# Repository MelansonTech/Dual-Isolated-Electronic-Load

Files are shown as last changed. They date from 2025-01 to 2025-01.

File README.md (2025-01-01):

# Dual Isolated Electronic Load
 Project: Dual Module Electronic Load with Voltage/Current Ranges and Nextion Touchscreen UI Overview: This project involves the design and development of a dual module electronic load system, which allows users to simulate a variable load on a power supply or battery. The system is capable of handling three distinct voltage levels (400V, 60V, and 20V) and three current ranges (0.35A, 3A, and 10A), offering flexibility for testing a wide range of power supplies and devices. The system incorporates a Nextion touchscreen UI for an intuitive and interactive user experience, enabling users to easily control and monitor the parameters of each module.  Key Features: Dual Module Design: Two independent load modules that can operate separately or in tandem, providing flexibility for different applications. Selectable Voltage and Current Ranges: The system supports three voltage levels (400V, 60V, and 20V) and three current ranges (0.35A, 3A, and 10A) for both modules. Nextion Touchscreen Interface: A user-friendly touchscreen interface that displays real-time data and allows users to control the load settings, select voltage and current ranges, and view system status. High Precision and Accuracy: The design ensures that the voltage and current are accurately regulated, making it suitable for testing power supplies, batteries, and other electronic components. System Components: Nextion Touchscreen: An HMI (Human-Machine Interface) touchscreen that provides an interactive interface for setting and monitoring the load parameters. The touchscreen is connected to the controller, allowing the user to select the voltage and current range for each module. Dual Electronic Load Modules: Each module is capable of handling the specified voltage and current ranges. These modules have precise control circuitry for drawing the desired current from the power source. Controller Circuit: A microcontroller (e.g., Arduino or STM32) processes inputs from the touchscreen and adjusts the load's resistance to regulate the current and voltage as per the selected settings. Power Handling Circuitry: The load modules include MOSFETs, resistors, and current-sensing components to handle the power dissipation for each voltage/current range. Cooling System: Due to the potential heat dissipation in high-power testing, the system includes passive or active cooling mechanisms such as heatsinks or fans. Working Principle: Voltage and Current Control: Each module has a set of switches or digital potentiometers to control the voltage and current. The user selects the desired voltage level (400V, 60V, or 20V) and the corresponding current range (0.35A, 3A, or 10A) using the Nextion touchscreen UI.  Load Regulation: The microcontroller processes the user inputs and adjusts the internal control circuitry (e.g., PWM control for MOSFETs) to simulate the required load on the power supply. This ensures that the current drawn is within the selected range while maintaining the appropriate voltage level.  Nextion Touchscreen Interface: The touchscreen displays real-time information, including:  Selected voltage and current range for both modules Real-time voltage, current, and power measurements Operational status, including any error or fault conditions Graphical representation of load performance (optional) The touchscreen allows the user to dynamically change the load settings and immediately observe the effects.  Feedback Loop: The system continuously monitors the output from the load modules, adjusting the load resistance to maintain the target current. The microcontroller is also responsible for ensuring the load operates within safe thermal limits by regulating the current drawn.  Applications: Power Supply Testing: Perfect for testing and simulating loads on power supplies with varying output voltage and current capabilities. Battery Testing: Ideal for testing battery discharge characteristics across different current ranges and voltages. Prototyping and R&D: Useful in research and development environments for testing power devices and components with adjustable load conditions. Quality Assurance and Validation: Can be used in production environments to validate the performance of power electronics devices, ensuring they meet voltage and current specifications. Design Considerations: Precision Control: The system must maintain accurate voltage and current regulation, especially when switching between different voltage and current ranges. Heat Dissipation: Since electronic loads can dissipate significant power as heat, the design must ensure proper thermal management, especially for higher voltage/current settings. Safety: The system must incorporate over-voltage, over-current, and over-temperature protection to ensure safe operation, especially when dealing with high voltages (e.g., 400V). User Interface: The Nextion touchscreen UI should be intuitive, with clear labeling, graphical representation of real-time data, and responsive controls for easy operation. Power Supply: The design needs to support a high-power input for the load modules, ensuring stable and reliable operation when high current and voltage are required. Challenges: Voltage Isolation: Ensuring safe operation at high voltages (up to 400V) requires proper isolation between control circuits and high-voltage components to prevent damage or injury. Load Switching: The system needs to ensure smooth transitions between voltage/current ranges to avoid sudden spikes or disruptions in the load. Thermal Management: Managing heat generated by high-current operation is crucial to ensure the longevity and stability of the electronic load modules. Conclusion: This Dual Module Electronic Load with Nextion Touchscreen UI represents a versatile, user-friendly solution for testing power supplies, batteries, and other electrical systems across a range of voltage and current levels. The integration of a Nextion touchscreen enhances the user experience, providing real-time monitoring and easy configuration of the load settings. Whether used in research, development, or quality assurance, this electronic load system provides a reliable and precise solution for simulating various load conditions.

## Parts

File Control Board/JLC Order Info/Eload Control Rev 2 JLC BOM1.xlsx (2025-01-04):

Comment | Designator | Footprint | LCSC Part #（optional）
Capacitor; Ceramic; Cap 0.1 uF; Tol 5%; Vol-Rtg 50 VDC; SMT; 0805; X7R; Tape & Reel | C1, C2, C3, C4, C5, C6,C7, C8, C12, C13, C14, C15, C16, C17, C19, C20, C21, C22, C23, C24, C25, C26, C29, C31, C32, C37, C38, C39, C40,C9 | 0805_C | C49678
Cap,SMD,MLCC,2.2uF 25V X7R 10%,0805 | C10, C33, C34, C35, C36,C18, C28 | 0805_C | C49217
CAP CER 10PF 50V C0G/NP0 0805 | C30 | 0805_C | C1785
RES SMD 10K OHM 1% 1/8W 0805 | R1, R2, R5, R6, R25, R26 | 0805_R | C17414
CHIP RESISTOR - SURFACE MOUNT 3.3KOHMS ±1% 1/8W 0805 ROHS | R13, R14, R15, R18, R19, R20, R21 | 0805_R | C26010
RES SMD 33 OHM 5% 1/8W 0805 | R16, R17 | 0805_R | C17634
CHIP RESISTOR - SURFACE MOUNT 22KOHMS ±1% 1/8W 0805 ROHS | R22, R24 | 0805_R | C17560
100 kOhms ±1% 0.125W, 1/8W Chip Resistor 0805 (2012 Metric) Thick Film | R23 | 0805_R | C17407
Res Thick Film 0805 1K Ohm 5% 0.125W(1/8W) ±200ppm/C Molded SMD Automotive Paper T/R | R3, R4, R7, R8, R9, R10,R11 | 0805_R | C17513

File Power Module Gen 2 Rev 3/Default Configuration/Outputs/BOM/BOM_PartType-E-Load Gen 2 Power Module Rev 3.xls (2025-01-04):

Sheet: BOM Report
Bill of Materials |  |  | <Parameter Title not found>
Source Data From: |  | E-Load Gen 2 Power Module Rev 3.PrjPcb
Project: |  | E-Load Gen 2 Power Module Rev 3.PrjPcb
Variant: |  | None
Creation Date: | 4/10/2021 | 2:47:32 PM
Print Date: | 2021-04-10 | 14:47:53
Production Quantity: | 100
Currency | CAD
Footprint | Comment | LibRef | Designator | Description | Quantity | Supplier 1 | Supplier Part Number 1 | Supplier Unit Price 1 | Supplier Order Qty 1 | Supplier Subtotal 1 | Manufacturer 1 | Manufacturer Part Number 1
Cap,0805 | Cap | Cap,0805,100nf,50V,5%,08055C104JAT2A | C1, C2, C3 | Capacitor; Ceramic; Cap 0.1 uF; Tol 5%; Vol-Rtg 50 VDC; SMT; 0805; X7R; Tape & Reel | 3
SOD123 | MMSZ4705T1G | diode,Zener, 18V,500mW, SOD123,MMSZ4705T1G | D2 | Zener Diode 18V 500mW ±5% Surface Mount SOD-123 | 1
4-ESIP with Heat Sink | Vishay PB3510-E3/45 | diode, bridge, 35A, 1000V, PB3510-E3/45 | DB1 | RECTIFIER BRIDGE 1000V 35A PB | 1 | Newark
Fuse,TH,Vertical,0505030.MXEP | FUSE CERAMIC 30A 500VAC/VDC 3AB | Fuse,30A,500VAC/VDC,Leaded | F1, F2 | FUSE CERAMIC 30A 500VAC/VDC 3AB | 2
Connector,TE,3-Pin,Male,Vert,2-644861-3 | 2-644861-3 | Conntector, though hole, TE, 3pin, 2.54mm,2-644861-3 | J1 | Connector Header Through Hole 3 position 0.100" (2.54mm) | 1
Keystone 8197 | wire teminal, lugs, screw, Keystone 8197 | wire teminal, lugs, screw, Keystone 8197 | J2, J3, J4, J5 | WRIGHT TOOL 8197 Socket, 1 In Dr, 3-1/8 In, 12 Pt, Std. More details: Socket, Drive Size 1 In., Number of Points 12, ... | 4
conn, molex, 0.1", 4 pin | 0022112042 | Connector,Through Hole,Molex,2.54mm,4Pin,Vert | J6 | Connector Header Through Hole 4 position 0.100" (2.54mm) | 1
Conn, JST, 4 pin, 2mm spacing Right Angle | JST B4B-PH-K-S(LF)(SN) | Conntector, though hole, JST, 4pin, 2mm,B4B-PH-K-S(LF)(SN) | J7 | PH Series 4 Position 2 mm Pitch Through Hole Crimp Top Entry Shrouded Header | 1 | Farnell
Standoff,Hex,M3,8mm | M3 hex Standoff | Standoff, M3, Hex | M1, M2, M3, M4, M5 | HEX STANDOFF M3,generic | 5
Mod,ELoad Gen 2 Rev 1 Support | Support PCBA | Mod,Eload Gen 2 rev 1 Support and Control | MOD1 | Eload Gen 2 Support PCBA | 1
NTC,TH,2.54mm Lead Spacing,NTCLE100E3103JT2 | NTCLE100E3103JT2 | Sensor,Temp,NTC,10Kohm,0.75%, NTCLE100E3103JT2 | NTC1 | THERMISTOR NTC 10KOHM 3977K BEAD | 1
DUAL TO-247-RA WITH HEATSINK | Diode | CC Load Power Module | PM1 | Dual RA Mosfet TO-247 with CPU cooler | 1
SOT23-3 | 2N7002ET1G | MOSFET,N-Channel,SOT23,0.25A,60V,2N7002ET1G | Q1, Q2, Q3 | Small Signal MOSFET, 60 V, 310 mA, Single, N-Channel, 3-Pin SOT-23, Pb-Free, Tape and Reel | 3 | Digi-Key | 2N7002ET1GOSCT-ND | 0.12501 | 300 | $37.50 | ON Semiconductor | 2N7002ET1G
DPAK,3-Leads | Infineon IRFR8314TRPBF | Mosfet,Dpak, Nchannel,90A,30V, IRFR8314TRPBF | Q4, Q5, Q6, Q7 | Single N-Channel 30 V 2.2 mOhm 36 nC HEXFET® Power Mosfet - DPAK | 4
Res 2512 | Res1 | Res,2512,10mO,3.00W,±1%,CRA2512-FZ-R010ELF | R1, R2 | Resistor; Metal Film; Res 0.01 Ohms; Pwr-Rtg 3 W; Tol 1%; SMT; 2512; Current Sense | 2
Fuse,PTC,10mmPitch,Radial, Disc | PTR030V0800-BK | Fuse,Resettable,8A,30V,ThoughHole,PTR030V0800-BK | R3, R10 | PTC RESET FUSE 30V 8A RADIAL | 2 | Digi-Key | PTR030V0800-BK-ND | 0.67933 | 200 | $135.87 | Eaton Bussmann | PTR030V0800-BK
Shunt,2512,SMD,Kalvin conn | Ohmite LVM25FVR030E-TR | Res, 2512, shunt, 30mO,1W, LVM25FVR030E-TR | R4 | Resistors; Current Sense; SMD 1W 0.030 OHM 1% | 1
Res,1206 | Res,1206,0.330Ohm,shunt,0.75W,1%,50ppm,KRL1632E-M-R330-F-T5 | Res,1206,0.330Ohm,shunt,0.75W,1%,50ppm,KRL1632E-M-R330-F-T5 | R5 | RES 0.33 OHM 1% 3/4W 1206 | 1 | Digi-Key | 408-1588-1-ND | 0.23144 | 100 | $23.14 | Susumu | KRL1632E-M-R330-F-T5
Res,2827,4W | CSSH2728FT10L0 | Res,2827,shunt,10mO,1%,15ppm,CSSH2728FT10L0 | R6 | 10 mOhms ±1% 4W Chip Resistor Wide 2827 (7067 Metric), 2728 Automotive AEC-Q200, Current Sense Metal Foil | 1
res, 0805, HD | Vishay / Dale CRCW080510K0FKTA | Res,0805,10.0kO,1%,100 ppm,CRCW080510K0FKTA | R7, R8, R9 | RES SMD 10K OHM 1% 1/8W 0805 | 3
 |  |  |  |  | 39 |  |  |  |  | $196.51
Approved |  | Notes

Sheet: Project Information
Project Full Path | E:\OneDrive\Shawn\electronic load\Circuit Studio\Rev 2\Power Module Gen 2 Rev 3\E-Load Gen 2 Power Module Rev 3.PrjPcb
Project Filename | E-Load Gen 2 Power Module Rev 3.PrjPcb
Variant Name | None
Data-Source Filename | E-Load Gen 2 Power Module Rev 3.PrjPcb
Data-Source Full Path | E:\OneDrive\Shawn\electronic load\Circuit Studio\Rev 2\Power Module Gen 2 Rev 3\E-Load Gen 2 Power Module Rev 3.PrjPcb
Title | <Parameter Title not found>
Total Quantity | 39
Report Time | 2:47:32 PM
Report Date | 4/10/2021
Report Date & Tine | 4/10/2021 2:47:32 PM
Output Name | BOM_PartType
Output Type | BOM_PartType
Output Generator Name | BOM
Output Generator Description | Bill of Materials

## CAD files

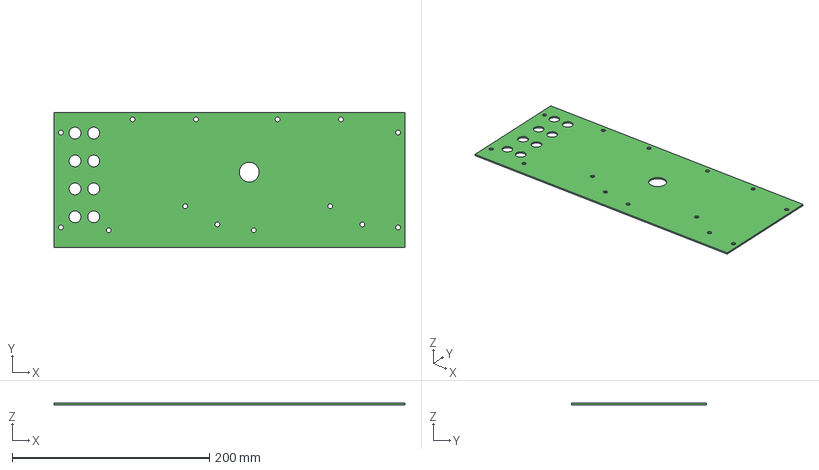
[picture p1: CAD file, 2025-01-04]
3D CAD Files/Gen 2 rev 2/Eload Gen 2 front panel Rev 2.step
356.0 x 137.0 x 1.65 mm

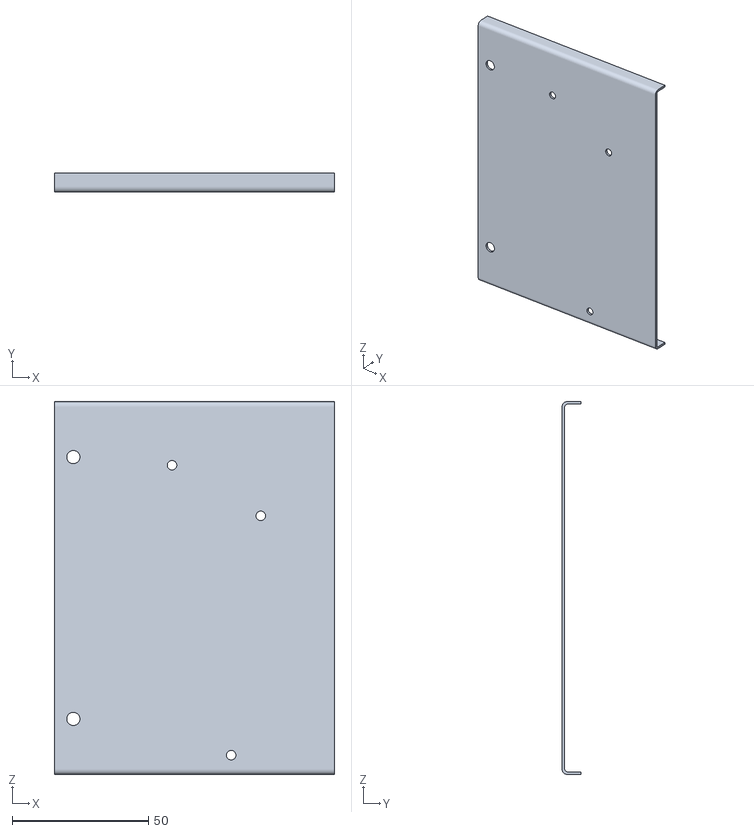
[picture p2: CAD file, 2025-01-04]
3D CAD Files/Gen 2 rev 2/STLs/Front mounting panel - test prints/Body1.stl
103.0 x 7.00 x 137.0

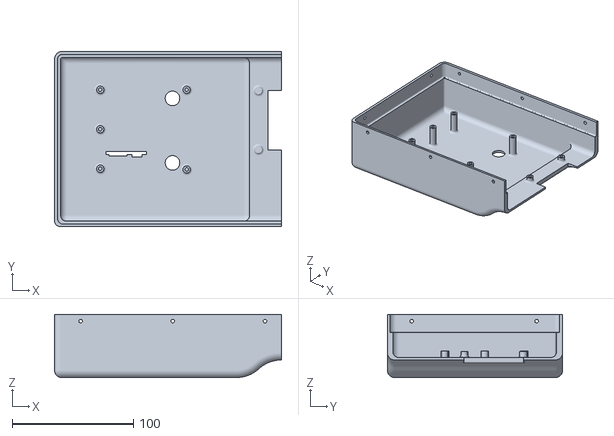
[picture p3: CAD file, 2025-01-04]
3D CAD Files/Gen 2 rev 2/STLs/Front Panel pt3.stl
187.1 x 144.5 x 52.0

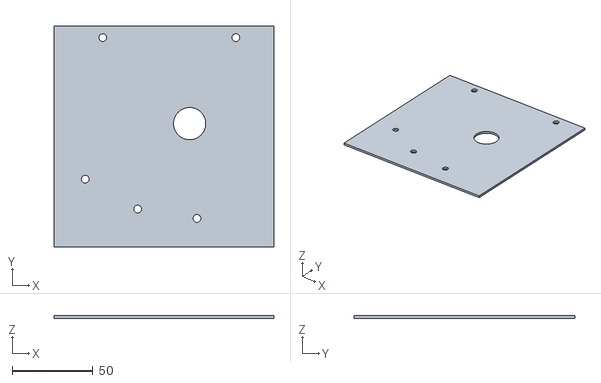
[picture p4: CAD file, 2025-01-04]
3D CAD Files/Gen 2 rev 2/STLs/PCB Front Panel/Body3.stl
136.6 x 137.0 x 1.65

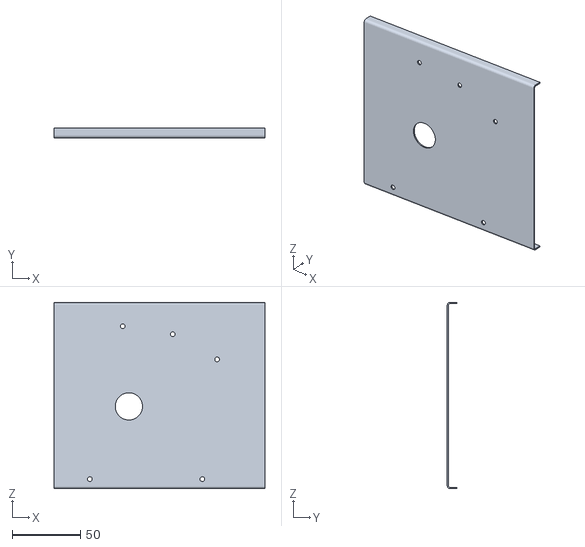
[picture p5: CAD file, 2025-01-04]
3D CAD Files/Gen 2 rev 2/STLs/Front mounting panel - test prints/Body3.stl
155.0 x 7.00 x 137.0

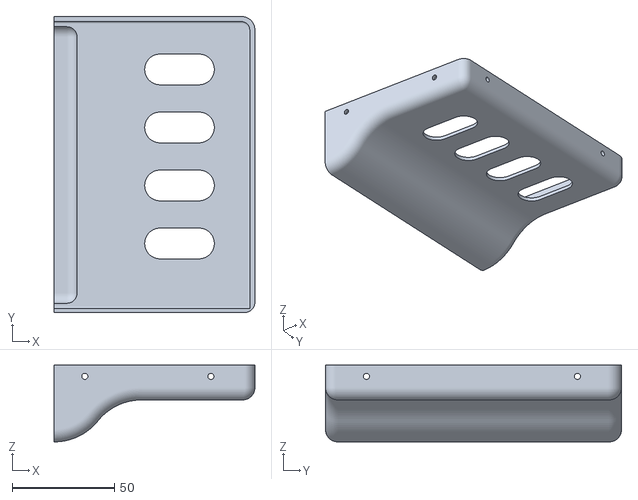
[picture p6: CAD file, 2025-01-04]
3D CAD Files/Gen 2 rev 2/STLs/Front Panel pt1.stl
98.0 x 144.5 x 37.5

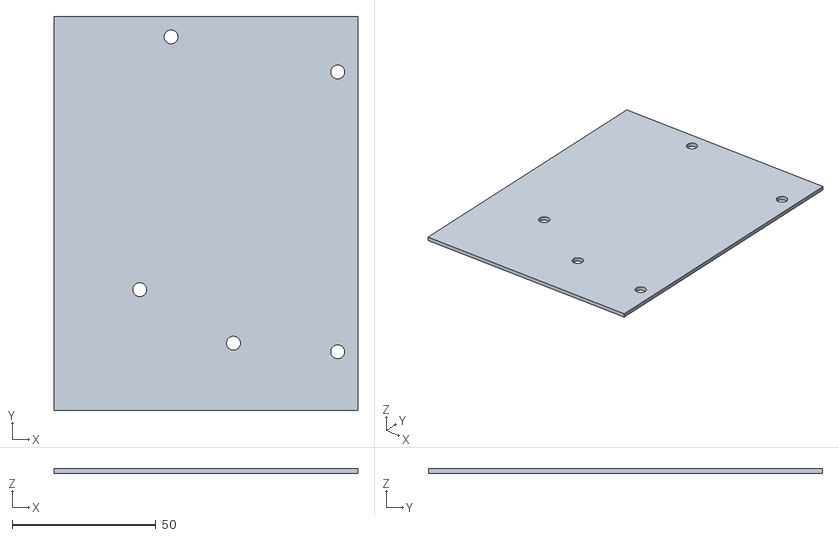
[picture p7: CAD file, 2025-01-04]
3D CAD Files/Gen 2 rev 2/STLs/PCB Front Panel/Body1.stl
105.6 x 137.0 x 1.65

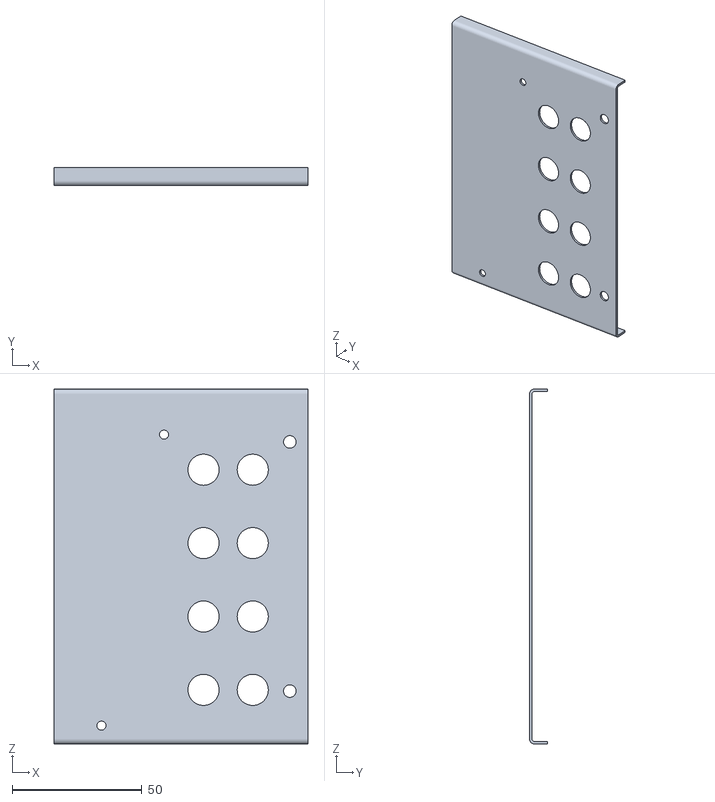
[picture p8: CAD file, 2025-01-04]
3D CAD Files/Gen 2 rev 2/STLs/Front mounting panel - test prints/Body2.stl
98.0 x 7.00 x 137.0

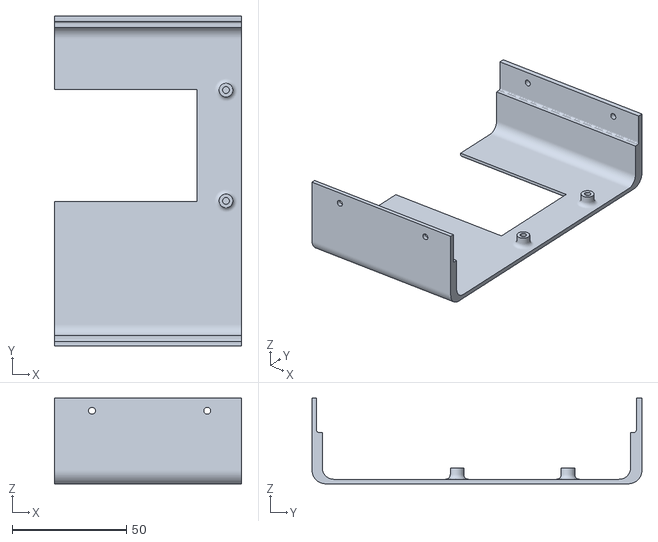
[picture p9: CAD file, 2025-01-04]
3D CAD Files/Gen 2 rev 2/STLs/Front Panel pt2.stl
81.9 x 144.5 x 37.5

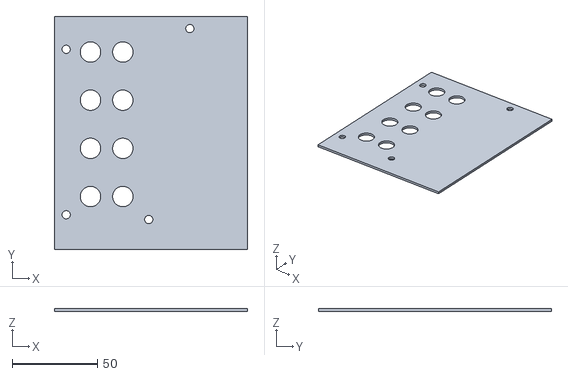
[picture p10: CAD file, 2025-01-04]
3D CAD Files/Gen 2 rev 2/STLs/PCB Front Panel/Body2.stl
113.8 x 137.0 x 1.65

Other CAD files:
3D CAD Files/Gen 2 rev 2/Eload Gen 2 front panel Rev 1.step

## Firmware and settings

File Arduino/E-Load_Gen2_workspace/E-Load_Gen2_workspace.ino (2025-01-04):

#include <SD_t3.h>

// inclue teensy IIC library Files

#include <i2c_t3.h>

//encoder library file

#include <Encoder.h>

//SD card library files

#include <SPI.h>
#include <SD.h>


// Nextion display library files

#include <Nextion.h>
#include <SoftwareSerial.h>
#define HWserial Serial1
#define DBserial Serial

// initialize the encoder by associating any needed encoder interface pins
// encoder pin use definitions

const int CCWA = 27, CWA = 28;
const int CCWB = 2, CWB = 30;
Encoder LDA_Knob(CCWA, CWA);
Encoder LDB_Knob(CCWB, CWB);

// setup digial PIN use definitions

const int LDA_PB = 29;                // LDA Encoder P\B on\off push button
const int LDB_PB = 14;                // LDB Encoder P\B on\off push button
const int SDcard_CS = 10;             // SD card chip select

// ***IIC Pin Use definitions

const int IICData = 18;
const int IICCLK = 19;

// IIC Variables

int LDA_ADD = 0x44; //LDA IIC address
int LDB_ADD = 0x54; //LDA IIC address

#define SetPointChange      0x10
#define modeChange          0x20
#define onOffStateChange    0x30
#define voltRangeChange     0x40
#define currentRangeChange  0x50
#define ADCReadingVolt      0x60
#define ADCReadingCurrent   0x70
#define ADCReadingTemp      0x80
#define ADCReadingRequest   0x90
#define RangeStatusRequest  0xA0


// digi-POT Load A Constants
const int potADD_1 = B0101111;; //I2C address of digital pot 2 (U2)(Write)Load A
const int potADD_2 = B0101110; //I2C address of digital pot 2 (U2)(Write)Load B
const int potInstrucSelB =  0x80; //Instuction POT B Select
const int potInstrucSelA =  0x00; //Instuction POT A Select
const int potInstrucReset = B01000000; //Instuction Reset
const int potInstrucSD =    B00100000; //Instuction ShutDownSelect
const int potInstrucO1 =    B00010000; //Instuction O1 State Change
const int potInstrucO2 =    B00001000; //Instuction O2 State Change

const int Vamp_Range_Low = 0xAF;
const int Vamp_Range_Med = 0x46;
const int Vamp_Range_High = 0x0A;

const float CSLowandVSHIGH = 2500; // Constant resistance Gain
const float CSLowandVSLow = 130; // Constant resistance Gain
const float Voffset = 1860;
float CR_SP_GAIN = CSLowandVSHIGH;

// Load limits

const float maxCurrentRangeLow = 0.35;
const float maxCurrentRangeMed = 3;
const float maxCurrentRangeHigh = 10;

const float VinMaxRangeHigh = 400;
const float VinMaxRangeMed = 60;
const float VinMaxRangeLow = 20;


//Moving average filteres sample size

//int MAF_sizeFast = 5;  // max value is 500 (array is set to 500)
int MAF_sizeSlow = 1; // max value is 500 (array is set to 500)

// SD Card Variables

unsigned int SD_log_count = 0;
unsigned int SD_ss_count = 0;
unsigned int long SD_log_active = 0;



// structs

struct VARS

{


  uint32_t capVal;
  bool StateNow;
  bool StateLast;
  float setVal;
  float calibrated;
  float calGain;
  float calOffset;
  float filteredFast;
  float filteredSlow;
  float ChangeDetectRef;
  // float ARRFast[1];
  float ARRSlow[50];
  int indexFast;
  int indexSlow;
  bool ChangeDetectFlag = 1;
  int range;
  String NexRecieve;
  float CalHighMeas;
  float CalLowMeas;
  float CalHighRead;
  float CalLowRead;
  float offsetRead;
  float offsetMeas;


};

struct SENSE {

  struct VARS SetPoint;
  struct VARS ENCODER;
  struct VARS temp;
  struct VARS volt;
  struct VARS current;
  struct VARS Power;
  struct VARS Mode;
  struct VARS Button;
  float power;
  float CurrentMax;
  int voltageLimit;
  int CurrentLimit;
  int SetPointLow;
  int SetPointHigh;
  int SetPointOffSet;
  String Units;

};


struct SENSE LDA;
struct SENSE LDB;

// nex dual state button cap variables

uint32_t LDACal = 0;
uint32_t LDBCal = 0;
uint32_t LDA_OnOff_State = 0;
uint32_t LDB_OnOff_State = 0;


// encoder variables

long newPositionA;
long newPositionB; // stores the encoder position afer a read
int pointerPosition; // used to set the position of the menu selection icon.

unsigned long int CurrentPage = 10;  // Nextion - Create a variable to store which page is currently loaded

//**************************button pressed flags

uint32_t CalVoltHighFlag = 0;
uint32_t CalVoltLowFlag = 0;

uint32_t CalAmpHighFlag = 0;
uint32_t CalAmpLowFlag = 0;

uint32_t tVoffSetFlag = 0;
uint32_t tIoffSetFlag = 0;

uint32_t bVrangeCalFlag = 0;
uint32_t bIrangeCalFlag = 0;

uint32_t bcaliVoltSlopeFlag = 0;
uint32_t bcaliVoltOffFlag = 0;

uint32_t bcaliCurrSlopeFlag = 0;
uint32_t bcaliCurrOffFlag = 0;

uint32_t CalVoffSetFlag = 0;
uint32_t CalIoffSetFlag = 0;

uint32_t BcalIDefFlag = 0;
uint32_t BcalVDefFlag = 0;

uint32_t KPEFlag = 0;
uint32_t KPXFlag = 0;

uint32_t KPAFlag = 0;
uint32_t KPBFlag = 0;

uint32_t dsbCaLIset = 0;

uint32_t LoadA_On_Off_BState_Cap = 0;
uint32_t LoadB_On_Off_BState_Cap = 0;
uint32_t LoadA_ModeSel_Cap = 0;
uint32_t LoadB_ModeSel_Cap = 0;
uint32_t LoadA_IrangeSel_Cap = 0;
uint32_t LoadB_IrangeSel_Cap = 0;
uint32_t LoadA_VrangeSel_Cap = 0;
uint32_t LoadB_VrangeSel_Cap = 0;



//**************************button pressed flags End

bool Relay_enable = 0;
bool RelayTimerStart = 0;

int RelayTimerRef = 0;
float Relay_onTime = 0;
float Relay_period = 0;

float overTemp = 60; // calibrated over temp fault threshold value
const float PowerLimit = -200; // calibrated over power fault threshold value

//***************************Nextion widget Declarations


//***********declare buttons

//page 1 buttons

NexButton PgSelStatic = NexButton(1, 1, "PgSelStatic");  // Button added
NexButton PgSelDyn = NexButton(1, 2, "PgSelDyn");  // Button added
NexButton PgSelAuto = NexButton(1, 3, "PgSelAuto");  // Button added
NexButton PgSelCal = NexButton(1, 4, "PgSelCal");  // Button added


//Page 2 buttons


NexDSButton LoadA_ON_OFF = NexDSButton(2, 5, "LoadA_ON_OFF");  // Button added
NexDSButton LoadB_ON_OFF = NexDSButton(2, 6, "LoadB_ON_OFF");  // Dual state button added

NexDSButton RunDataLog = NexDSButton(2, 27, "RunDataLog");  // Dual state button added
NexDSButton TakeSnapShot = NexDSButton(2, 33, "TakeSnapShot");  // Dual state button added




//Page 3 buttons

NexDSButton LDA_Bmode = NexDSButton(3, 2, "LDA_Bmode");  // Button added
NexDSButton LDB_Bmode = NexDSButton(3, 3, "LDB_Bmode");  // Button added
NexDSButton LDA_B_VR = NexDSButton(3, 7, "LDA_B_VR");  // Button added
NexDSButton LDB_B_VR = NexDSButton(3, 4 , "LDB_B_VR"); // Button added
NexDSButton LDA_B_IR = NexDSButton(3, 6, "LDA_B_IR");  // Button added
NexDSButton LDB_B_IR = NexDSButton(3, 5, "LDB_B_IR");  // Button added

//Page 4 buttons

NexDSButton bcaliVoltSlope = NexDSButton(4, 21, "bcaliVoltSlope");  // Button added
NexDSButton bcaliCurrSlope = NexDSButton(4, 22, "bcaliCurrSlope");  // Button added
NexDSButton BcalVDef = NexDSButton(4, 23, "BcalVDef"); // Button added
NexDSButton bcaliVoltOff = NexDSButton(4, 23, "bcaliVoltOff");  // Button added
NexDSButton bcaliCurrOff = NexDSButton(4, 25, "bcaliCurrOff");  // Button added
NexDSButton BcalIDef = NexDSButton(4, 26, "BcalIDef");  // Button added
NexDSButton dsbCalSetA = NexDSButton(4, 2, "dsbCalSetA");  // Dual state button added
NexDSButton dsbCalSetB = NexDSButton(4, 3, "dsbCalSetB");  // Dual state button added
NexDSButton bVrangeCal = NexDSButton(4, 19, "bVrangeCal");  // Dual state button added
NexDSButton bIrangeCal = NexDSButton(4, 20, "bIrangeCal");  // Dual state button added
NexDSButton dsbCalonOff = NexDSButton(4, 38, "dsbCalonOff");  // Dual state button added
NexDSButton dsbCaLIsetHigh = NexDSButton(4, 36, "dsbCaLIsetHigh");  // Dual state button added
NexDSButton dsbCaLIsetLow = NexDSButton(4, 37, "dsbCaLIsetLow");  // Dual state button added


// Declare Text Boxes

NexText tsetA = NexText(2, 17, "tsetA");  // Text box added, so we can read it
NexText tsetB = NexText(2, 18, "tsetB");  // Text box added, so we can read it

NexText tVcalSenH = NexText(4, 7, "tVcalSenH");  // Text box added, so we can read it
NexText tVcalSetH = NexText(4, 1, "tVcalSetH");  // Text box added, so we can read it
NexText tVcalSenL = NexText(4, 8, "tVcalSenL");  // Text box added, so we can read it
NexText tVcalSetL = NexText(4, 5, "tVcalSetL");  // Text box added, so we can read it
NexText tIcalSenH = NexText(4, 9, "tIcalSenH");  // Text box added, so we can read it
NexText tIcalSetH = NexText(4, 4, "tIcalSetH");  // Text box added, so we can read it
NexText tIcalSenL = NexText(4, 10, "tIcalSenL");  // Text box added, so we can read it
NexText tIcalSetL = NexText(4, 6, "tIcalSetL");  // Text box added, so we can read it
NexText tVoffSet = NexText(4, 28, "tVoffSet");  // Text box added, so we can read it
NexText tIoffSet = NexText(4, 29, "tIoffSet");  // Text box added, so we can read it

String nexTextBoxAddressBuff; 

//Declare variables

NexVariable VRL_SlopeA =  NexVariable(0, 3, "VRL_SlopeA");
NexVariable VRL_OffsetA =  NexVariable(0, 4, "VRL_OffsetA");
NexVariable IRL_SlopeA =  NexVariable(0, 2, "IRL_SlopeA");
NexVariable IRL_OffsetA =  NexVariable(0, 5, "IRL_OffsetA");

NexVariable VRM_SlopeA =  NexVariable(0, 6, "VRM_SlopeA");
NexVariable VRM_OffsetA =  NexVariable(0, 7, "VRM_OffsetA");
NexVariable IRM_SlopeA =  NexVariable(0, 9, "IRM_SlopeA");
NexVariable IRM_OffsetA =  NexVariable(0, 8, "IRM_OffsetA");

NexVariable VRH_SlopeA =  NexVariable(0, 10, "VRH_SlopeA");
NexVariable VRH_OffsetA =  NexVariable(0, 12, "VRH_OffsetA");
NexVariable IRH_SlopeA =  NexVariable(0, 11, "IRH_SlopeA");
NexVariable IRH_OffsetA =  NexVariable(0, 13, "IRH_OffsetA");

NexVariable VRL_SlopeB =  NexVariable(0, 15, "VRL_SlopeB");
NexVariable VRL_OffsetB =  NexVariable(0, 14, "VRL_OffsetB");
NexVariable IRL_SlopeB =  NexVariable(0, 16, "IRL_SlopeB");
NexVariable IRL_OffsetB =  NexVariable(0, 17, "IRL_OffsetB");

NexVariable VRM_SlopeB =  NexVariable(0, 18, "VRM_SlopeB");
NexVariable VRM_OffsetB =  NexVariable(0, 25, "VRM_OffsetB");
NexVariable IRM_SlopeB =  NexVariable(0, 19, "IRM_SlopeB");
NexVariable IRM_OffsetB =  NexVariable(0, 20, "IRM_OffsetB");

NexVariable VRH_SlopeB =  NexVariable(0, 21, "VRH_SlopeB");
NexVariable VRH_OffsetB =  NexVariable(0, 22, "VRH_OffsetB");
NexVariable IRH_SlopeB =  NexVariable(0, 24, "IRH_SlopeB");
NexVariable IRH_OffsetB =  NexVariable(0, 23, "IRH_OffsetB");

NexVariable SPL_SlopeA =  NexVariable(0, 25, "SPL_SlopeA");
NexVariable SPL_SlopeB =  NexVariable(0, 26, "SPL_SlopeB");
NexVariable SPM_SlopeA =  NexVariable(0, 27, "SPM_SlopeA");
NexVariable SPM_SlopeB =  NexVariable(0, 28, "SPM_SlopeB");
NexVariable SPH_SlopeA =  NexVariable(0, 29, "SPH_SlopeA");
NexVariable SPH_SlopeB =  NexVariable(0, 30, "SPH_SlopeB");

NexVariable SPL_OffsetA =  NexVariable(0, 31, "SPL_OffsetA");
NexVariable SPL_OffsetB =  NexVariable(0, 32, "SPL_OffsetB");
NexVariable SPM_OffsetA =  NexVariable(0, 33, "SPM_OffsetA");
NexVariable SPM_OffsetB =  NexVariable(0, 34, "SPM_OffsetB");
NexVariable SPH_OffsetA =  NexVariable(0, 35, "SPH_OffsetA");
NexVariable SPH_OffsetB =  NexVariable(0, 36, "SPH_OffsetB");

NexVariable CalSetVoltHigh =  NexVariable(4, 20, "CalSetVoltHigh");
NexVariable CalSetVoltLow =  NexVariable(4, 21, "CalSetVoltLow");

NexVariable CalSetAmpHigh =  NexVariable(4, 22, "CalSetAmpHigh");
NexVariable CalSetAmpLow =  NexVariable(4, 23, "CalSetAmpLow");

NexVariable CalVoffSet =  NexVariable(4, 30, "CalVoffSet");
NexVariable CalIoffSet =  NexVariable(4, 31, "CalIoffSet");

NexVariable KPX =  NexVariable(4, 35, "KPX");
NexVariable KPE =  NexVariable(4, 34, "KPE");
NexVariable KPA =  NexVariable(2, 20, "KPA");
NexVariable KPB =  NexVariable(2, 21, "KPB");

char buffer[100] = {0};  // This is needed only if you are going to receive a text from the display. You can remove it otherwise.
// Further on this sketch I do receive text so that's why I created this buffer.

// Declare temp sense lookup table Arrays
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
void loop() {

  DBserial.println("Main Loop");

  CurrentPage = currentNexPage();


  // Set Defaults


  switch (CurrentPage) {

    case 0:

      break;

    case 1:

      break;

    case 2:

      Load_Monitor_Loop(); // go to the load monitoring loop

      break;

    case 3:

      DualLoadSetupLoop(); // go to the load setup loop

      break;

    case 4:

      LoadCalibrationLoop();

      break;
  } //end of current page if statement

  delay(25);
}//end of main arduino loop

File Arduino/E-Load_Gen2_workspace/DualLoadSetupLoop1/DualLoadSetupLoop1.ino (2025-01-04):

void DualLoadSetup(void) {


  //********************************************Load A Mode Config*****************************************

  if (LoadA_ModeSel_Cap == 1) {

    LoadA_ModeSel_Cap = 0; // change the button pressed polling flag back to zero

    LDA_Bmode.setValue(LoadA_ModeSel_Cap);// reset the dual state button value back to zero

    DBserial.println("LDA_SelectMode");

    LDA.Mode.range += 1;

    if (LDA.Mode.range > 2) {
      LDA.Mode.range  = 0;
    }

    switch (LDA.Mode.range) {

      case 0:

        DBserial.println(LDA.Mode.range);
        HWserial.print("LDA_Bmode.txt=");  // Update the nex display
        HWserial.print("\"");
        HWserial.print("CC");  // Update the nex display
        HWserial.print("\"");
        HWserial.write(0xff);  // We always have to send this three lines after each command sent to the nextion display.
        HWserial.write(0xff);
        HWserial.write(0xff);

        break;

      case 1:

        HWserial.print("LDA_Bmode.txt=");  // Update the nex display
        HWserial.print("\"");
        HWserial.print("CR");  // Update the nex display
        HWserial.print("\"");
        HWserial.write(0xff);  // We always have to send this three lines after each command sent to the nextion display.
        HWserial.write(0xff);
        HWserial.write(0xff);

        break;

      case 2:

        HWserial.print("LDA_Bmode.txt=");  // Update the nex display
        HWserial.print("\"");
        HWserial.print("CP");  // Update the nex display
        HWserial.print("\"");
        HWserial.write(0xff);  // We always have to send this three lines after each command sent to the nextion display.
        HWserial.write(0xff);
        HWserial.write(0xff);

        break;

    }//end of LDA mode switch case
  }

  //********************************************Load B Mode Config*****************************************
  if (LoadB_ModeSel_Cap == 1) {

    LoadB_ModeSel_Cap = 0; // change the button pressed polling flag back to zero
    LDB_Bmode.setValue(LoadB_ModeSel_Cap);// reset the dual state button value back to zero


    LDB.Mode.range += 1;

    if (LDB.Mode.range > 2) {

      LDB.Mode.range  = 0;

    }

    switch (LDB.Mode.range) {

      case 0:

        DBserial.println(LDB.Mode.range);
        HWserial.print("LDB_Bmode.txt=");  // Update the nex display
        HWserial.print("\"");
        HWserial.print("CC");  // Update the nex display
        HWserial.print("\"");
        HWserial.write(0xff);  // We always have to send this three lines after each command sent to the nextion display.
        HWserial.write(0xff);
        HWserial.write(0xff);

        break;

      case 1:

        DBserial.println(LDB.Mode.range);
        DBserial.print("mode 1");
        HWserial.print("LDB_Bmode.txt=");  // Update the nex display
        HWserial.print("\"");
        HWserial.print("CR");  // Update the nex display
        HWserial.print("\"");
        HWserial.write(0xff);  // We always have to send this three lines after each command sent to the nextion display.
        HWserial.write(0xff);
        HWserial.write(0xff);

        break;

      case 2:

        HWserial.print("LDB_Bmode.txt=");  // Update the nex display
        HWserial.print("\"");
        HWserial.print("CP");  // Update the nex display
        HWserial.print("\"");
        HWserial.write(0xff);  // We always have to send this three lines after each command sent to the nextion display.
        HWserial.write(0xff);
        HWserial.write(0xff);

        break;

    }//end of LDB mode switch case
  }

  //********************************************Load A Voltage Range Config*****************************************

  if (LoadA_VrangeSel_Cap == 1) {

    LoadA_VrangeSel_Cap = 0; // change the button pressed polling flag back to zero

    LDA_Bmode.setValue(LoadA_VrangeSel_Cap);// reset the dual state button value back to zero

    DBserial.println("LDA_Voltage Range");
    LDA.volt.range += 1;

    if (LDA.volt.range > 2) {

      LDA.volt.range  = 0;

    }

    switch (LDA.volt.range) {

      case 0:

        LDA.current.range = 0;
        HWserial.print("LDA_B_IR.txt=");  // Update the nex display
        HWserial.print("\"");
        HWserial.print("0.5A");  // Update the nex display
        HWserial.print("\"");
        HWserial.write(0xff);  // We always have to send this three lines after each command sent to the nextion display.
        HWserial.write(0xff);
        HWserial.write(0xff);

        HWserial.println(LDA.volt.range);
        HWserial.print("LDA_B_VR.txt=");  // Update the nex display
        HWserial.print("\"");
        HWserial.print("400V");  // Update the nex display
        HWserial.print("\"");
        HWserial.write(0xff);  // We always have to send this three lines after each command sent to the nextion display.
        HWserial.write(0xff);
        HWserial.write(0xff);

        Wire.beginTransmission(LDA_ADD); //U1B
        Wire.write(voltRangeChange);
        Wire.write(1);   // sends instruction byte  - Set digital pot reference to ground
        Wire.endTransmission();     // stop transmitting
        
        Wire.beginTransmission(potADD_1); //U1B
        Wire.write(potInstrucSelA);   // sends instruction byte
        Wire.write(Vamp_Range_High);  // sends potentiometer value byte
        Wire.endTransmission();     // stop transmitting

        Wire.beginTransmission(potADD_1); //U1B
        Wire.write(potInstrucSelB);   // sends instruction byte
        Wire.write(Vamp_Range_High);  // sends potentiometer value byte
        Wire.endTransmission();     // stop transmitting

        Wire.beginTransmission(LDA_ADD); //U1B
        Wire.write(voltRangeChange);
        Wire.write(0);   // sends instruction byte  - Set digital pot reference to 1.5Vdc
        Wire.endTransmission();     // stop transmitting

        // set default config of the load B to high voltage range

        //  Wire.beginTransmission(potADD_2); //U1B
        //  Wire.write(potInstrucSelA);   // sends instruction byte
        //  Wire.write(Vamp_Range_High);  // sends potentiometer value byte
        //  Wire.endTransmission();     // stop transmitting
        //
        //  Wire.beginTransmission(potADD_2); //U1B
        //  Wire.write(potInstrucSelB);   // sends instruction byte
        //  Wire.write(Vamp_Range_High);  // sends potentiometer value byte
        //  Wire.endTransmission();     // stop transmitting

        break;

      case 1:

        if (LDA.current.range > 1) {

          LDA.current.range = 1;
          HWserial.print("LDA_B_IR.txt=");  // Update the nex display
          HWserial.print("\"");
          HWserial.print("2A");  // Update the nex display
          HWserial.print("\"");
          HWserial.write(0xff);  // We always have to send this three lines after each command sent to the nextion display.
          HWserial.write(0xff);
          HWserial.write(0xff);

        }
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
